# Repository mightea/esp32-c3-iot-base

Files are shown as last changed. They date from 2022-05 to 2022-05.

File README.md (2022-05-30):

# esp32-iot-base

ESP32-WROOM-32E based IoT development board for [ESPHome](https://esphome.io/) designed with [KiCad EDA](https://www.kicad.org/)

<p style="background-color:yellow">
<font color="black"> ⚠️  Work in progress...</font>
</p>

## Project Status

This board is still in it's early design phase...

- [x] Design basic PCB layout
- [x] Generate fabrication data
- [x] Fabicate prototypes
- [ ] Test prototypes (rev. 0.2)

The intention was to use the ESP32-C3 SOC but arduino and esphome support for this generation of chips currently in an early stage and therfore the ESP32-WROOM-32E is used in the meantime.

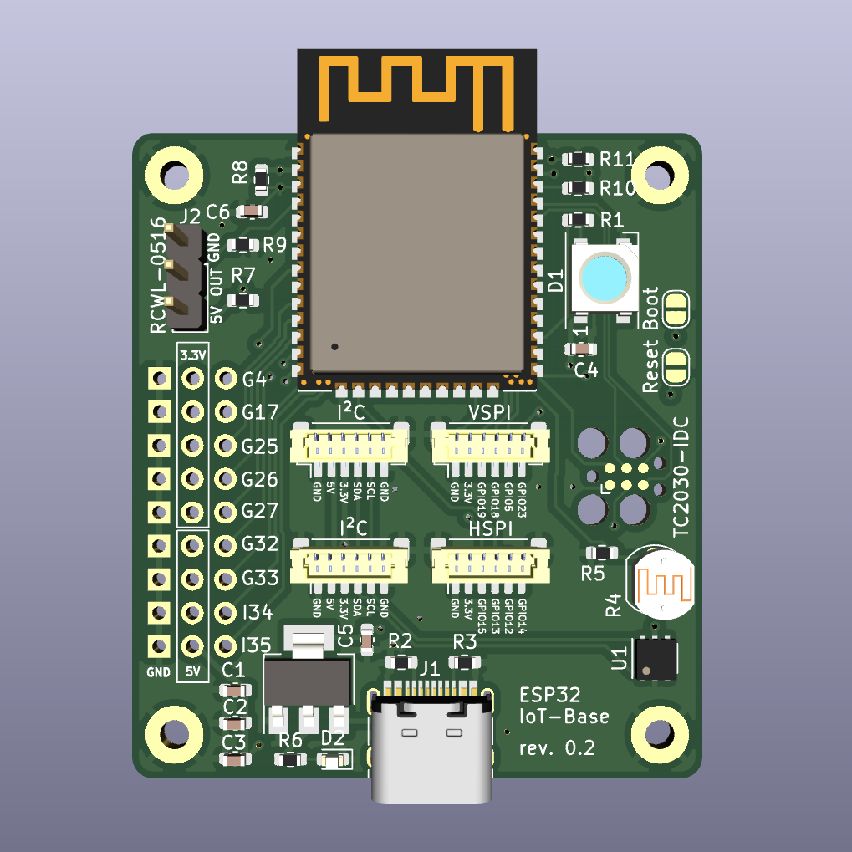
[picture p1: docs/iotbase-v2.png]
iot-base-v1


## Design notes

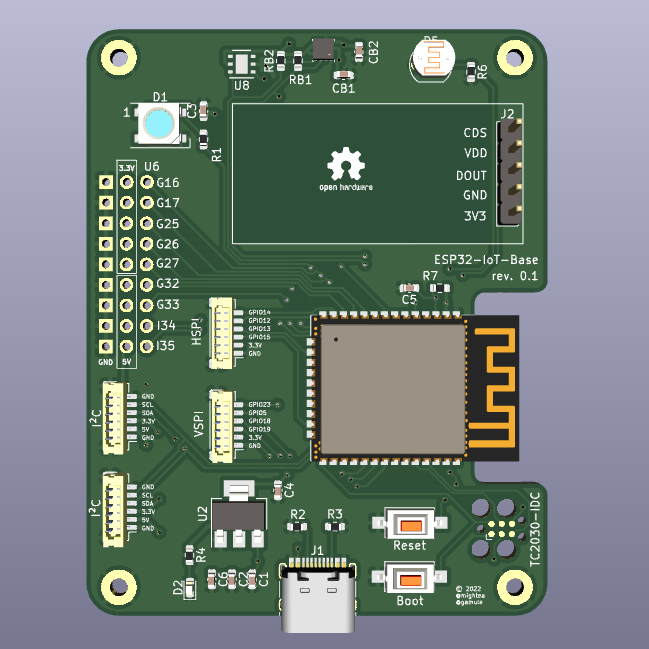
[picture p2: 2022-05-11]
docs/iotbase-v1.png

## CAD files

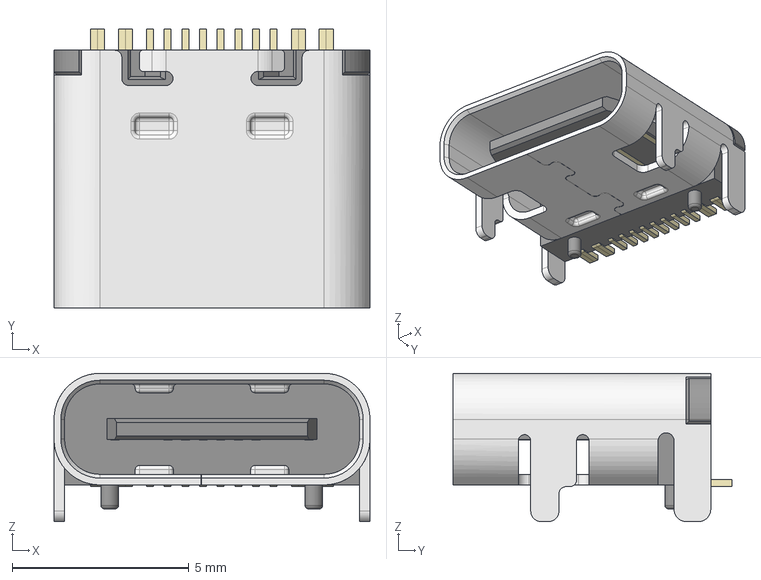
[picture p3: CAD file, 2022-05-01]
pcb/3dmodels/USB_C_Receptacle_HRO_TYPE-C-31-M-12.step
8.95 x 7.90 x 4.20 mm

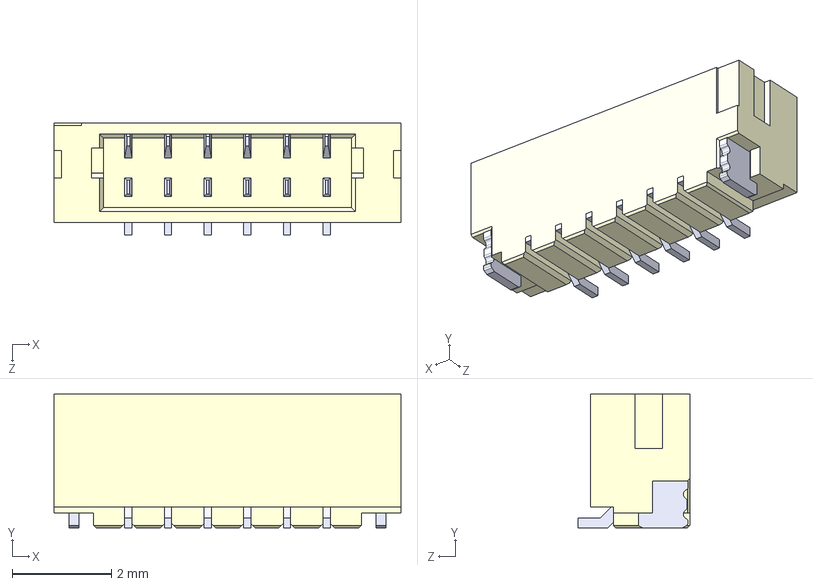
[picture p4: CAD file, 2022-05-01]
pcb/3dmodels/BM06B-SURS-TF-LF--SN---3DModel-STEP-56544.STEP
7.00 x 2.70 x 2.25 mm

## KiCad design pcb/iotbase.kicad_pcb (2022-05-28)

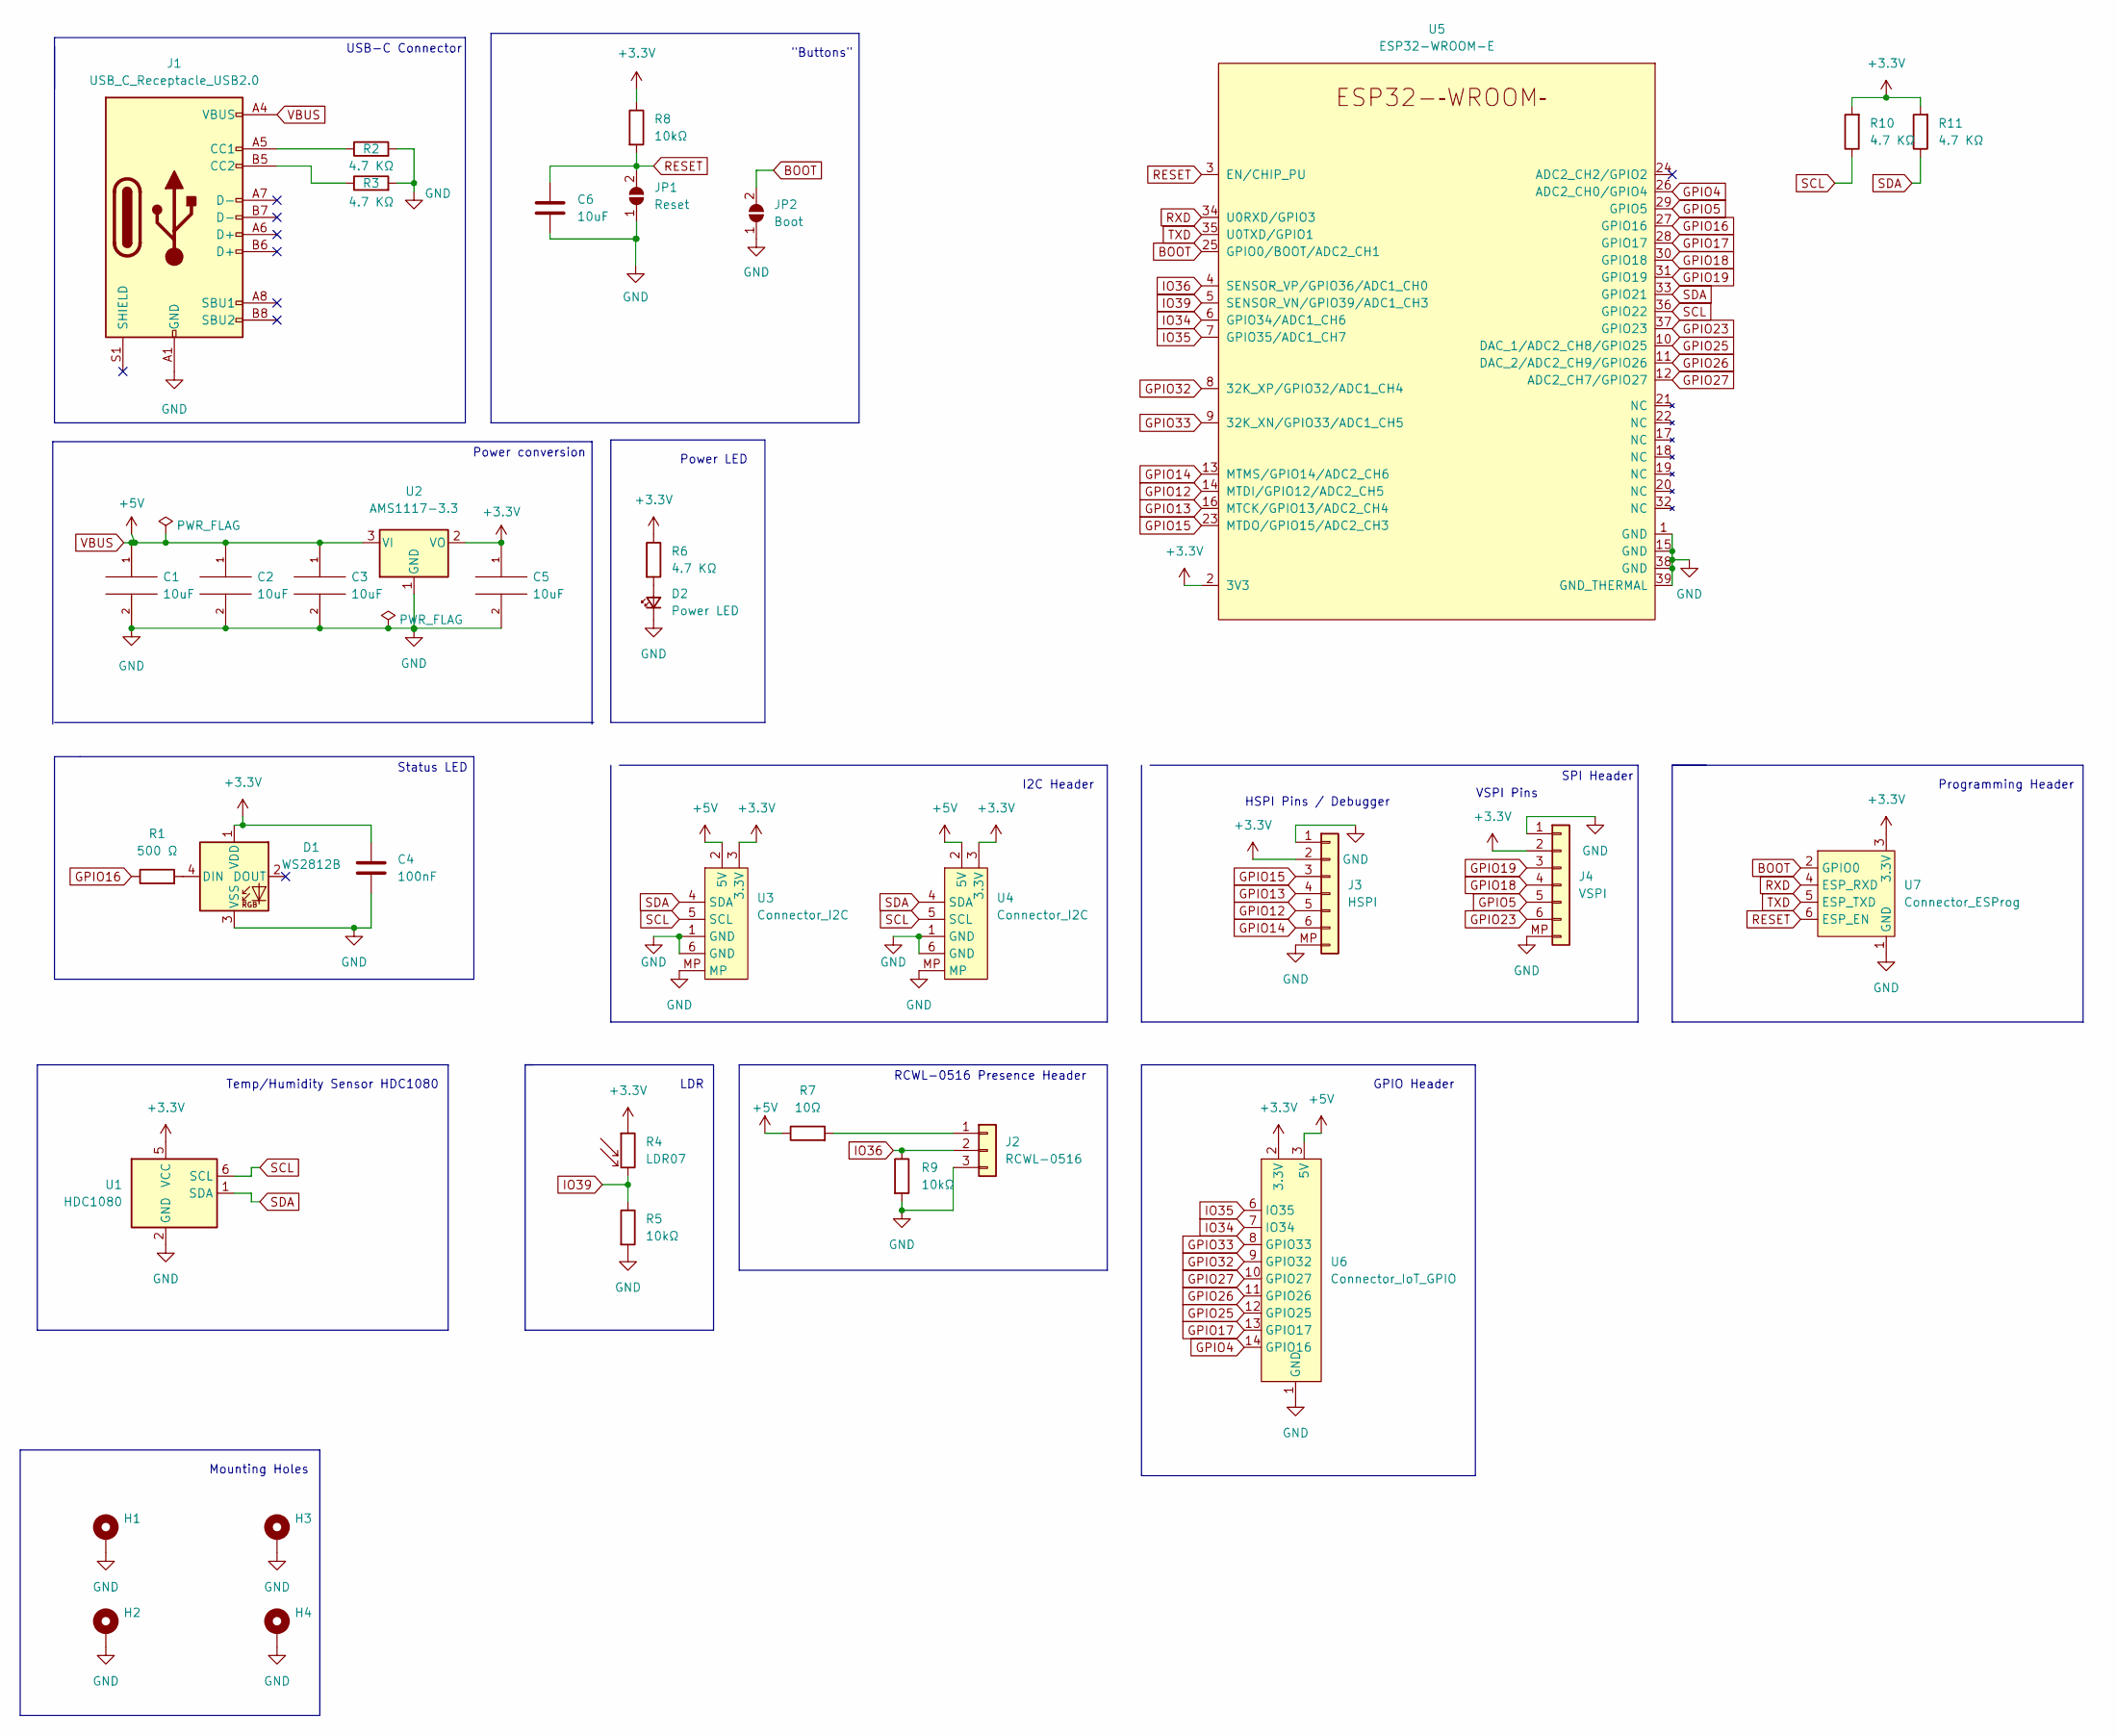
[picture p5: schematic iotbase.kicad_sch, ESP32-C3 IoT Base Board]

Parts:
C1, C2, C3, C5, C6: 10uF; C_0603_1608Metric
C4: 100nF; C_0603_1608Metric
D1: WS2812B; LED_WS2812B_PLCC4_5.0x5.0mm_P3.2mm
D2: Power LED; LED_0603_1608Metric
H1, H2, H3, H4: MountingHole_Pad; MountingHole_2.2mm_M2_Pad
J1: USB_C_Receptacle_USB2.0; USB_C_Receptacle_HRO_TYPE-C-31-M-12
J2: RCWL-0516; PinHeader_1x03_P2.54mm_Vertical
J3: HSPI; JST_SH_BM06B-SRSS-TB_1x06-1MP_P1.00mm_Vertical
J4: VSPI; JST_SH_BM06B-SRSS-TB_1x06-1MP_P1.00mm_Vertical
JP1: Reset; SolderJumper-2_P1.3mm_Open_RoundedPad1.0x1.5mm
JP2: Boot; SolderJumper-2_P1.3mm_Open_RoundedPad1.0x1.5mm
R1: 500 Ω; R_0603_1608Metric
R2, R3, R10, R11: 4.7 KΩ; R_0603_1608Metric
R4: LDR07; R_LDR_5.1x4.3mm_P3.4mm_Vertical
R5, R8, R9: 10kΩ; R_0603_1608Metric
R6: 4.7 KΩ; R_0603_1608Metric; jlcpcb C25905
R7: 10Ω; R_0603_1608Metric
U1: HDC1080; Texas_PWSON-N6
U2: AMS1117-3.3; SOT-223-3_TabPin2
U3, U4: Connector_I2C; JST_SH_BM06B-SRSS-TB_1x06-1MP_P1.00mm_Vertical
U5: ESP32-WROOM-E; ESP32-WROOM-32E
U6: Connector_IoT_GPIO
U7: Connector_ESProg; Tag-Connect_TC2030-IDC-FP_2x03_P1.27mm_Vertical

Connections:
+3V3: C4.1, C5.1, D1.1 (VDD), J3.2, J4.2, R4.1, R6.1, R8.1, R10.2, R11.2, U1.5 (VCC), U2.2 (VO), U3.3 (3.3V), U4.3 (3.3V), U5.2 (3V3), U6.2 (3.3V), U7.3 (3.3V)
BOOT: JP2.2 (B), U5.25 (GPIO0/BOOT/ADC2_CH1), U7.2 (GPIO0)
GND: C1.2, C2.2, C3.2, C4.2, C5.2, C6.2, D1.3 (VSS), D2.1 (K), H1.1, H2.1, H3.1, H4.1, J1.A1 (GND), J1.A12 (GND), J1.B1 (GND), J1.B12 (GND), J2.3, J3.1, J3.MP, J4.1, J4.MP, JP1.1 (A), JP2.1 (A), R2.2, R3.2, R5.2, R9.2, U1.2 (GND), U2.1 (GND), U3.1 (GND), U3.6 (GND), U3.MP, U4.1 (GND), U4.6 (GND), U4.MP, U5.1 (GND), U5.15 (GND), U5.38 (GND), U5.39 (GND_THERMAL), U6.1 (GND), U7.1 (GND)
GPIO4: U5.26 (ADC2_CH0/GPIO4), U6.14 (GPIO16)
GPIO5: J4.5, U5.29 (GPIO5)
GPIO12: J3.5, U5.14 (MTDI/GPIO12/ADC2_CH5)
GPIO13: J3.4, U5.16 (MTCK/GPIO13/ADC2_CH4)
GPIO14: J3.6, U5.13 (MTMS/GPIO14/ADC2_CH6)
GPIO15: J3.3, U5.23 (MTDO/GPIO15/ADC2_CH3)
GPIO16: R1.1, U5.27 (GPIO16)
GPIO17: U5.28 (GPIO17), U6.13 (GPIO17)
GPIO18: J4.4, U5.30 (GPIO18)
GPIO19: J4.3, U5.31 (GPIO19)
GPIO23: J4.6, U5.37 (GPIO23)
GPIO25: U5.10 (DAC_1/ADC2_CH8/GPIO25), U6.12 (GPIO25)
GPIO26: U5.11 (DAC_2/ADC2_CH9/GPIO26), U6.11 (GPIO26)
GPIO27: U5.12 (ADC2_CH7/GPIO27), U6.10 (GPIO27)
GPIO32: U5.8 (32K_XP/GPIO32/ADC1_CH4), U6.9 (GPIO32)
GPIO33: U5.9 (32K_XN/GPIO33/ADC1_CH5), U6.8 (GPIO33)
IO34: U5.6 (GPIO34/ADC1_CH6), U6.7 (IO34)
IO35: U5.7 (GPIO35/ADC1_CH7), U6.6 (IO35)
IO36: J2.2, R9.1, U5.4 (SENSOR_VP/GPIO36/ADC1_CH0)
IO39: R4.2, R5.1, U5.5 (SENSOR_VN/GPIO39/ADC1_CH3)
unnamed: D1.4 (DIN), R1.2
unnamed: D2.2 (A), R6.2
unnamed: J1.A5 (CC1), R2.1
unnamed: J1.B5 (CC2), R3.1
unnamed: J2.1, R7.2
RESET: C6.1, JP1.2 (B), R8.2, U5.3 (EN/CHIP_PU), U7.6 (ESP_EN)
RXD: U5.34 (U0RXD/GPIO3), U7.4 (ESP_RXD)
SCL: R10.1, U1.6 (SCL), U3.5 (SCL), U4.5 (SCL), U5.36 (GPIO22)
SDA: R11.1, U1.1 (SDA), U3.4 (SDA), U4.4 (SDA), U5.33 (GPIO21)
TXD: U5.35 (U0TXD/GPIO1), U7.5 (ESP_TXD)
VBUS: C1.1, C2.1, C3.1, J1.A4 (VBUS), J1.A9 (VBUS), J1.B4 (VBUS), J1.B9 (VBUS), R7.1, U2.3 (VI), U3.2 (5V), U4.2 (5V), U6.3 (5V)

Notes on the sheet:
Power LED
HSPI Pins / Debugger
Temp/Humidity Sensor HDC1080
Mounting Holes
Programming Header
I2C Header
USB-C Connector
VSPI Pins
"Buttons"
RCWL-0516 Presence Header
LDR
Power conversion
Status LED
SPI Header
GPIO Header

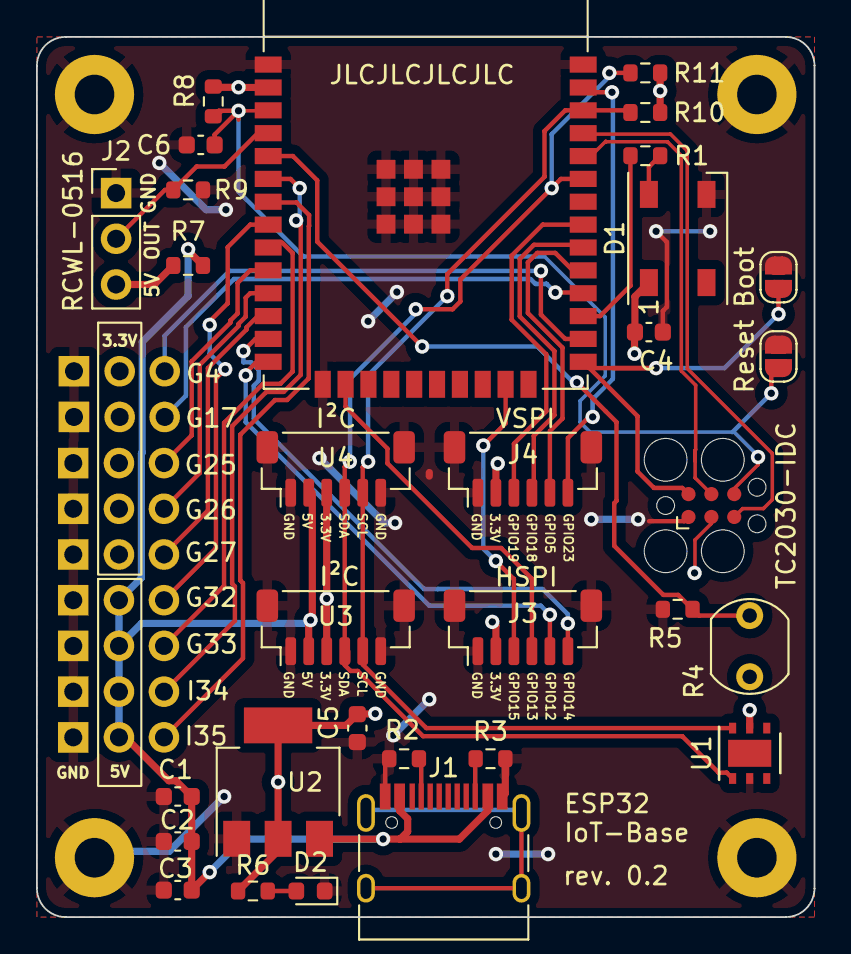
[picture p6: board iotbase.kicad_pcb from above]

Board: 2 copper layers, 43.2 x 48.9 mm, 36 parts (0 on the bottom side), 34 nets.

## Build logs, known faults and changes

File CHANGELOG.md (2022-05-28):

# Changelog

All notable changes to this project will be documented in this file.

The format is based on [Keep a Changelog](https://keepachangelog.com/en/1.0.0/)

<!-- markdownlint-disable no-duplicate-header -->

## [Unreleased]

### Added

### Changed

### Removed

### Fixed

## [0.2] - 2022-05-28

### Added

- Added changelog
- Adds Pi-filter and resistor to RCWL05-16
- Added new header for externally connecting RCWL-05-16

### Changed

- Moved KiCad project to `pcb` folder
- Reduces board size
- Changed Boot and Reset buttons to Solder Pads to reduce cost

### Removed

- Removed BME280 to reduce cost
- Removed onboard RCWL05-16 due to RF issues

### Fixed

- Connects WS2812 led to 3.3v #3
- Fixes boot issues by updating C5 to 10uf #4

## [0.1] - 2022-05-11

### Added

- Initial fabrication release

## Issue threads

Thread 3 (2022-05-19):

WS2812B LED only works when powered trough the programmer

mightea, 2022-05-19:

mightea, 2022-05-20:
The issue seems to be that the LED need to be connected to 3.3V instead of VDD

Closed 2022-05-20.

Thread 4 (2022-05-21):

Stability and boot issues

mightea, 2022-05-21:
- Sometimes the code hangs after boot up and the devices has to be reset multiple times until it runns
- After longer periods of time it hangs as well and is unreachable

mightea, 2022-05-25:
Fixed by updating C5 to 10uf

Closed 2022-05-25.

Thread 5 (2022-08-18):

Change temperature & humidity sensor to Sensirion SHTC3

mightea, 2022-08-18:
https://jlcpcb.com/partdetail/Sensirion-SHTC3/C194656

mightea, 2023-02-24:
Switching to new sensor generation:  https://jlcpcb.com/partdetail/Sensirion-SHT40_AD1BR2/C2909890

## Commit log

2022-04-06 initial import
    [iotbase.kicad_pcb, iotbase.kicad_sch]
2022-04-08 adds additionals sensors and connectors
    [iotbase.kicad_pcb, iotbase.kicad_sch]
2022-04-08 header update
    [iotbase.kicad_sch]
2022-04-08 renames symbol and footprint libraries
    [iotbase.kicad_pcb, iotbase.kicad_sch]
2022-04-08 updates board layout adds header for RCWL-0516 updates readme
    [iotbase.kicad_pcb, iotbase.kicad_sch]
2022-04-08 routing and repositioning
    [iotbase.kicad_pcb]
2022-04-08 additional routing
    [iotbase.kicad_pcb]
2022-04-12 updates gpio connector adds additional traces adds jlcpcb fab plugin
    [iotbase.kicad_pcb, iotbase.kicad_sch]
2022-05-01 updates routes
    [BM06B-SURS-TF-LF--SN---3DModel-STEP-56544.STEP, USB_C_Receptacle_HRO_TYPE-C-31-M-12.step, iotbase.kicad_pcb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]
2022-05-04 updates additional routes
    [iotbase.kicad_pcb, iotbase.kicad_sch]
2022-05-10 updated components and layout.
    [iotbase.kicad_pcb, iotbase.kicad_sch]
2022-05-11 adds rounded corners adds connector pin silkscreens
    [iotbase.kicad_pcb, iotbase.kicad_sch]
2022-05-11 updates antenna area cutout adds jlcpcb label
    [iotbase.kicad_pcb]
2022-05-14 reorganized repo 🏗
    [BM06B-SURS-TF-LF--SN---3DModel-STEP-56544.STEP, USB_C_Receptacle_HRO_TYPE-C-31-M-12.step, iotbase.kicad_pcb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]
2022-05-20 connects WS2812 led to 3.3v, fixes #3
    [iotbase.kicad_pcb, iotbase.kicad_sch]
2022-05-25 fixes boot issues by updating C5 to 10uf
    [iotbase.kicad_pcb, iotbase.kicad_sch]
2022-05-28 reduced pcb size added header for RCWL-0516 removed BME280 to save on cost replaced buttons with solder pads
    [iotbase.kicad_pcb, iotbase.kicad_sch]
2022-05-28 fixes drc warnings ads rounded corners to rev.2 updates changelog
    [iotbase.kicad_pcb]
2022-05-28 updates jlcpcb compoent id's
    [iotbase.kicad_pcb, iotbase.kicad_sch]
2022-05-28 release rev. 0.2
    [iotbase.kicad_pcb, iotbase.kicad_sch]

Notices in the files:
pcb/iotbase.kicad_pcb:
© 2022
